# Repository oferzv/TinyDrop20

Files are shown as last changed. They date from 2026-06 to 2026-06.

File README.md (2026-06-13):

# TinyDrop20

TinyDrop20 is a small ATtiny85-based 5x4 charlieplexed LED matrix board. The
repository contains the PlatformIO firmware project, Eagle design files, and
manufacturing outputs for hardware revision `V1_1`.

## Project background

This project was created in collaboration with [@talofer99](https://github.com/talofer99)
as part of a series of free-time hardware and firmware projects we built years
ago. I decided to move these projects to GitHub in the hope that they may be
useful, educational, or inspiring to others.

This PCB revision was manufactured and tested.

## Repository layout

```text
Firmware/
  V1_1/
    platformio.ini      PlatformIO project configuration
    src/main.cpp        ATtiny85 firmware
    include/            Project headers, currently unused
    lib/                Project libraries, currently unused
    test/               PlatformIO test folder, currently unused

Hardware/
  V1_1/
    Eagle/              Eagle schematic and board files
    Manufacturing/
      GERBER/           Gerber package for PCB fabrication
      Schematic/        Exported schematic PDF
```

## Hardware overview

The V1.1 board is built around an `ATTINY85-20SU` microcontroller and a 20 LED
display arranged as a 5 row by 4 column matrix. The LEDs are 0603 green parts
driven through five 100 ohm resistors from ATtiny pins `PB0` through `PB4`.

Other notable hardware:

- 20 green 0603 matrix LEDs
- 1 red 0603 status LED
- ATtiny85 SOIC-8 microcontroller
- Five 100 ohm matrix resistors
- 10 kOhm reset pull-up resistor
- Micro USB connector
- MCP73831 battery charger circuit
- CR2450-size coin-cell holder footprint
- Six round test points for programming or probing
- 3.6 mm mounting pad

Power note: the schematic includes an MCP73831 Li-ion/LiPo charger and a battery
holder labeled `CR2450`. Standard CR2450 cells are not rechargeable. Before
connecting USB power with a cell installed, verify that the assembled board is
intended for a compatible rechargeable lithium coin cell, such as the exact cell
specified by the hardware build.

## Firmware overview

The firmware is an Arduino sketch built with PlatformIO for `attiny85` at
8 MHz. It drives the LEDs directly by changing ATtiny GPIO direction and output
state for charlieplexing.

Display constants in `Firmware/V1_1/src/main.cpp`:

```cpp
#define SPEED          35
#define DISPLAY_WIDTH  4
#define DISPLAY_HEIGHT 5
```

The sketch includes:

- A 4x5 bitmap font for uppercase letters, digits, space, `!`, `#`, `$`, and
  `^`
- `setLed()` and `setPixel()` helpers for charlieplexed LED control
- `renderCharacter()` and `renderString()` helpers for drawing text
- Several visual modes and effects:
  - `matrix_fill_test()`
  - `write_text()`
  - `scrolling_text()`
  - `screen_saver()`
  - `rainEffect()`
  - `rows_effect()`

The current sketch displays `myString`, defined near the top of `main.cpp`:

```cpp
char myString[] = "#$^";
```

In the checked-in firmware, `lastState` is hardcoded to `1`, so `setup()` sets
`mode = 0` and the main loop runs `matrix_fill_test()`. The EEPROM-based mode
toggle code is present but commented out.

## Build firmware

Install PlatformIO, then build from the firmware directory:

```powershell
cd Firmware\V1_1
pio run
```

Build output is generated under:

```text
Firmware/V1_1/.pio/build/attiny85/
```

The main outputs are `firmware.elf` and `firmware.hex`.

## Upload firmware

The PlatformIO environment is configured for a USBtiny-compatible ISP
programmer:

```ini
[env:attiny85]
platform = atmelavr
board = attiny85
framework = arduino
board_build.mcu = attiny85
board_build.f_cpu = 8000000L
upload_protocol = usbtiny
```

Connect the programmer to the ATtiny85 programming pads or test points, then
run:

```powershell
cd Firmware\V1_1
pio run -t upload
```

The Micro USB connector on the hardware is part of the board power and charger
circuit. The firmware configuration expects ISP programming with `usbtiny`, not
USB bootloader programming.

## Hardware files

Open the board in Autodesk Eagle/Fusion Electronics using:

```text
Hardware/V1_1/Eagle/TinyDrop20_V1_1.sch
Hardware/V1_1/Eagle/TinyDrop20_V1_1.brd
```

Manufacturing files are already exported:

```text
Hardware/V1_1/Manufacturing/GERBER/TinyDrop20_V1_1_2020_03_09.zip
Hardware/V1_1/Manufacturing/Schematic/TinyDrop20_V1_1.pdf
```

## Development notes

- The charlieplexing code uses ATtiny pins `0` through `4`, corresponding to
  `PB0` through `PB4` in the schematic.
- Only one LED is actively driven at a time. Persistent images are produced by
  repeatedly scanning pixels fast enough for persistence of vision.
- To show different text, update `myString` in `src/main.cpp`.
- To enable the text display mode, set `mode = 1` or re-enable the EEPROM mode
  selection logic.
- Generated PlatformIO build files under `.pio/` should not be committed.

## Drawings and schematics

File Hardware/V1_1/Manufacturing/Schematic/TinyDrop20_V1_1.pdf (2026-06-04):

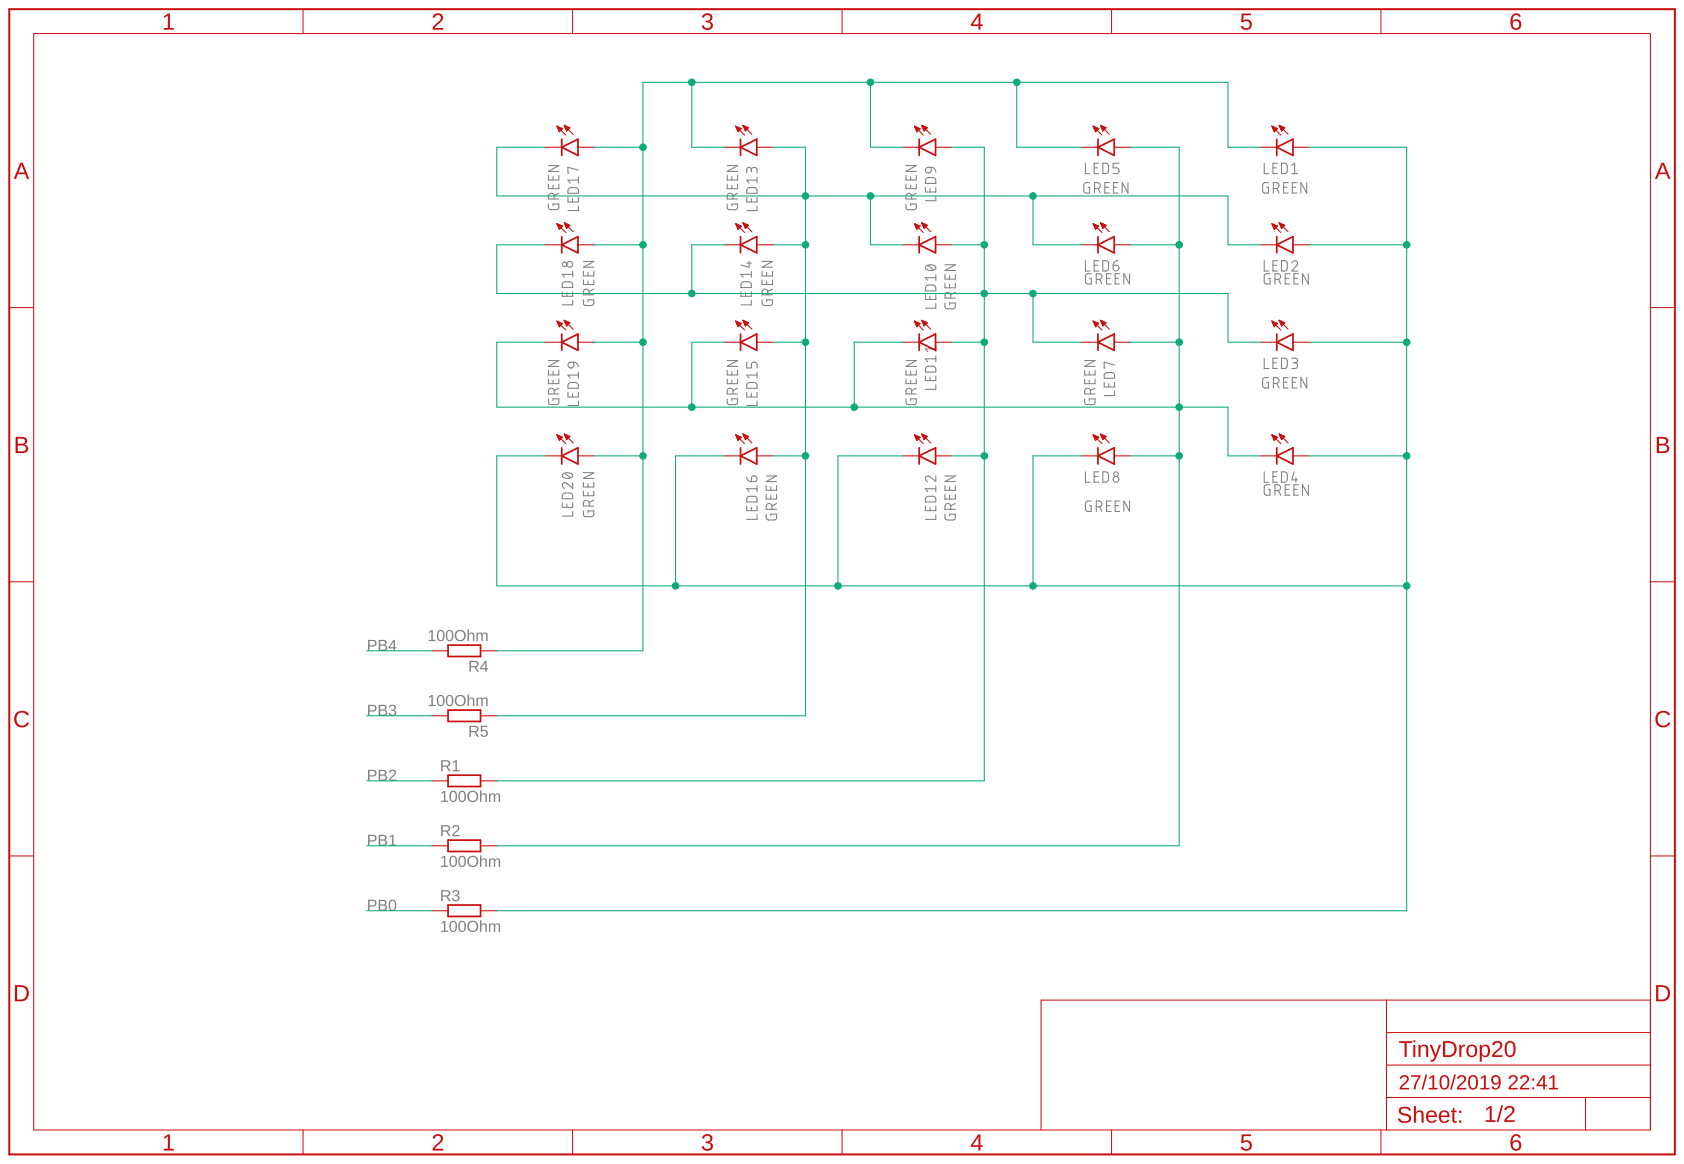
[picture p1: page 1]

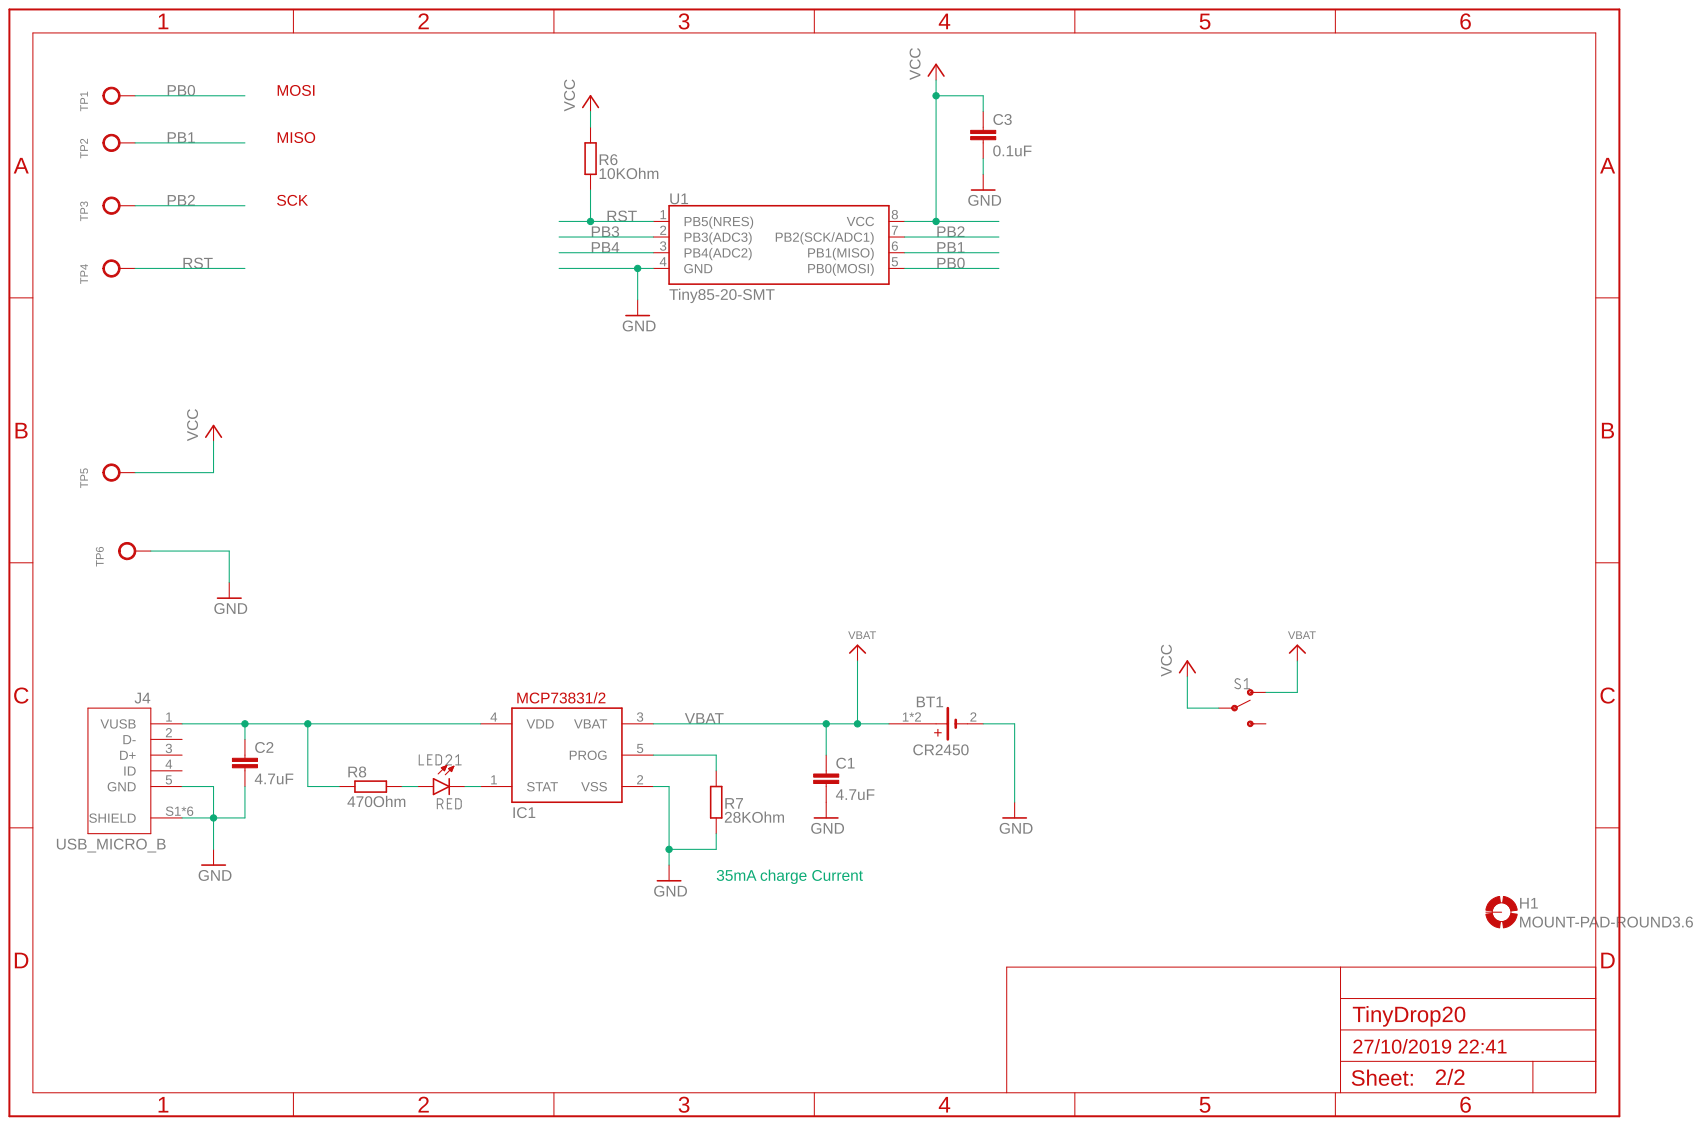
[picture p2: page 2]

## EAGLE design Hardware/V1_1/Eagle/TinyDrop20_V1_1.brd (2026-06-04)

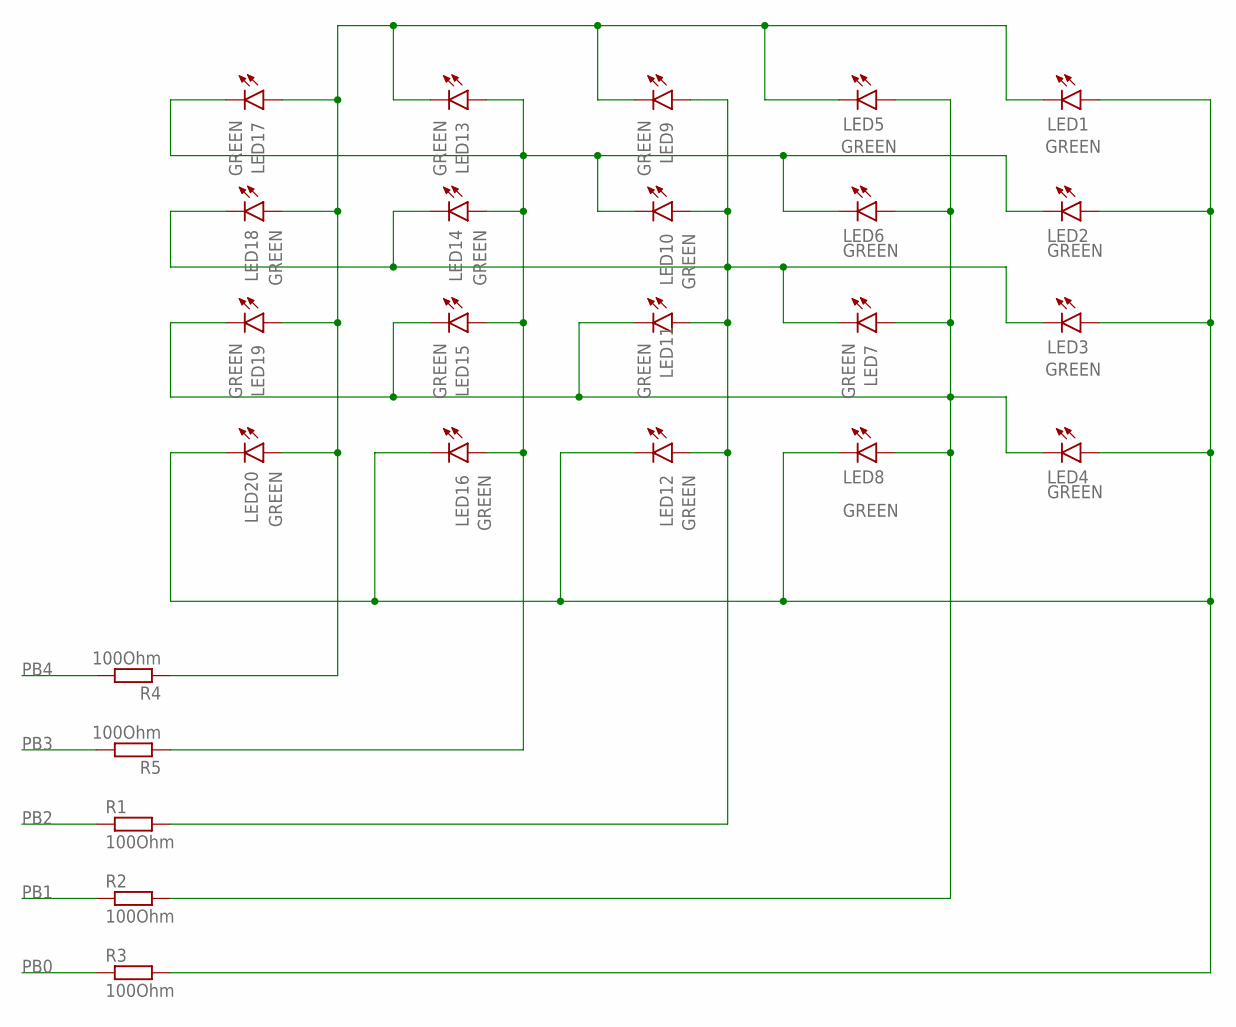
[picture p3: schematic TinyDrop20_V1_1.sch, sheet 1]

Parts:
LED1, LED2, LED3, LED4, LED5, LED6, LED7, LED8, LED9, LED10, LED11, LED12, LED13, LED14, LED15, LED16, LED17, LED18, LED19, LED20: GREEN; CHIPLED_0603
R1, R2, R3, R4, R5: 100Ohm; R0603

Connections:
unnamed: LED1.A, LED2.A, LED3.A, LED4.A, LED8.C, LED12.C, LED16.C, LED20.C, R3.2
unnamed: LED4.C, LED5.A, LED6.A, LED7.A, LED8.A, LED11.C, LED15.C, LED19.C, R2.2
unnamed: LED3.C, LED7.C, LED9.A, LED10.A, LED11.A, LED12.A, LED14.C, LED18.C, R1.2
unnamed: LED2.C, LED6.C, LED10.C, LED13.A, LED14.A, LED15.A, LED16.A, LED17.C, R5.1
unnamed: LED1.C, LED5.C, LED9.C, LED13.C, LED17.A, LED18.A, LED19.A, LED20.A, R4.1
PB0: R3.1; also elsewhere on the board
PB1: R2.1; also elsewhere on the board
PB2: R1.1; also elsewhere on the board
PB3: R5.2; also elsewhere on the board
PB4: R4.2; also elsewhere on the board

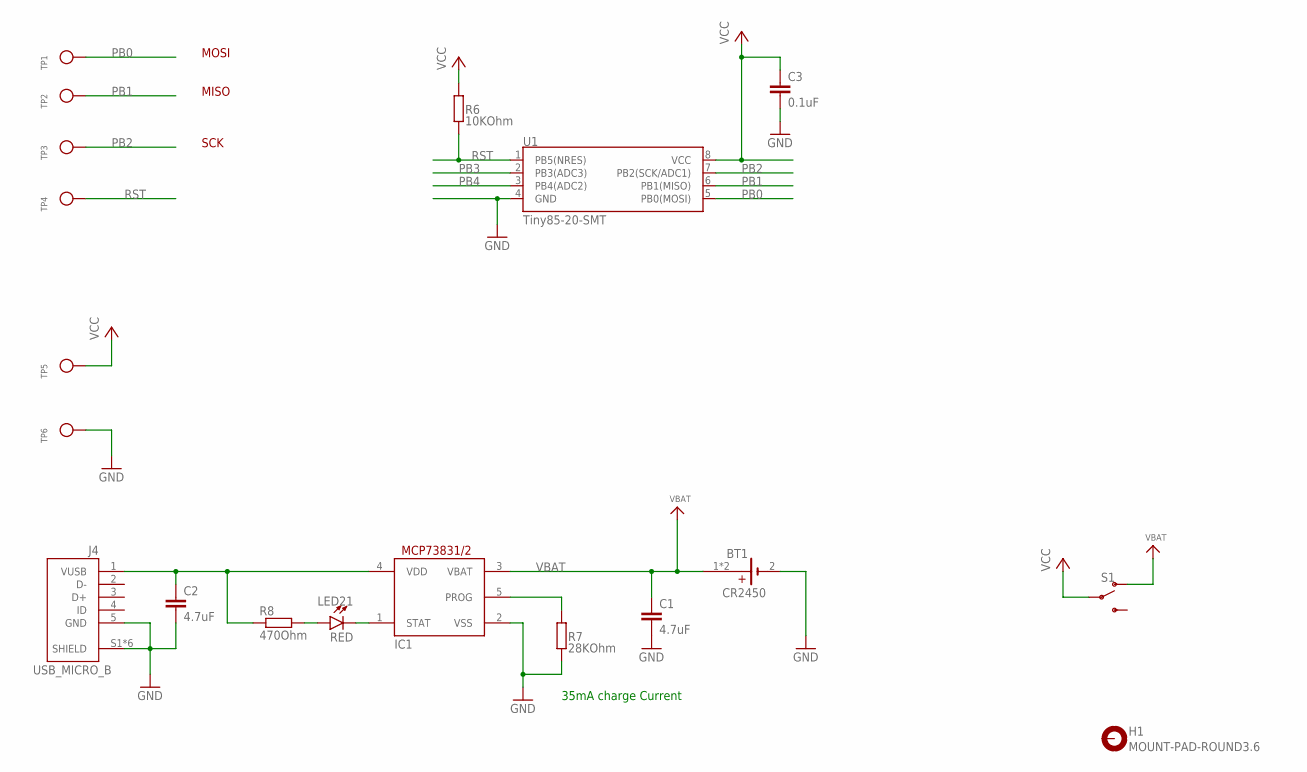
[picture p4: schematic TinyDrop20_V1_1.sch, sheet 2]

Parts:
BT1: CR2450; BATTCON_24.5X5MM_SMD
C1, C2: 4.7uF; C0805
C3: 0.1uF; C0805
H1: MOUNT-PAD-ROUND3.6; 3,6-PAD
IC1: MCP73831/OT; SOT23-5L
J4: USB_MICRO_B; FCI_10118193-0001LF
LED21: RED; CHIPLED_0603
R6: 10KOhm; R0603
R7: 28KOhm; R0603
R8: 470Ohm; R0603
S1: SWITCH-SPDT-SMD-RIGHT-ANGLE; SWITCH_SPST_SMD_A
TP1, TP2, TP3, TP4, TP5, TP6: TESTPOINTROUND2MM; TESTPOINT_ROUND_2MM
U1: Tiny85-20-SMT; SO08-EIAJ_MCU

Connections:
GND: BT1.2 (-), C1.2, C2.2, C3.2, IC1.2 (VSS), J4.5 (GND), J4.S1 (SHIELD), J4.S2 (SHIELD), J4.S3 (SHIELD), J4.S4 (SHIELD), J4.S5 (SHIELD), J4.S6 (SHIELD), R7.1, TP6.P$1, U1.4 (GND)
unnamed: IC1.5 (PROG), R7.2
unnamed: C2.1, IC1.4 (VDD), J4.1 (VUSB), R8.1
unnamed: IC1.1 (STAT), LED21.C
unnamed: LED21.A, R8.2
PB0: TP1.P$1, U1.5 (PB0(MOSI)); also elsewhere on the board
PB1: TP2.P$1, U1.6 (PB1(MISO)); also elsewhere on the board
PB2: TP3.P$1, U1.7 (PB2(SCK/ADC1)); also elsewhere on the board
PB3: U1.2 (PB3(ADC3)); also elsewhere on the board
PB4: U1.3 (PB4(ADC2)); also elsewhere on the board
RST: R6.1, TP4.P$1, U1.1 (PB5(NRES))
VBAT: BT1.1 (+), BT1.3 (+), C1.1, IC1.3 (VBAT), S1.1 (O)
VCC: C3.1, R6.2, S1.2, TP5.P$1, U1.8 (VCC)

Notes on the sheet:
35mA charge Current
MOSI
MISO
SCK

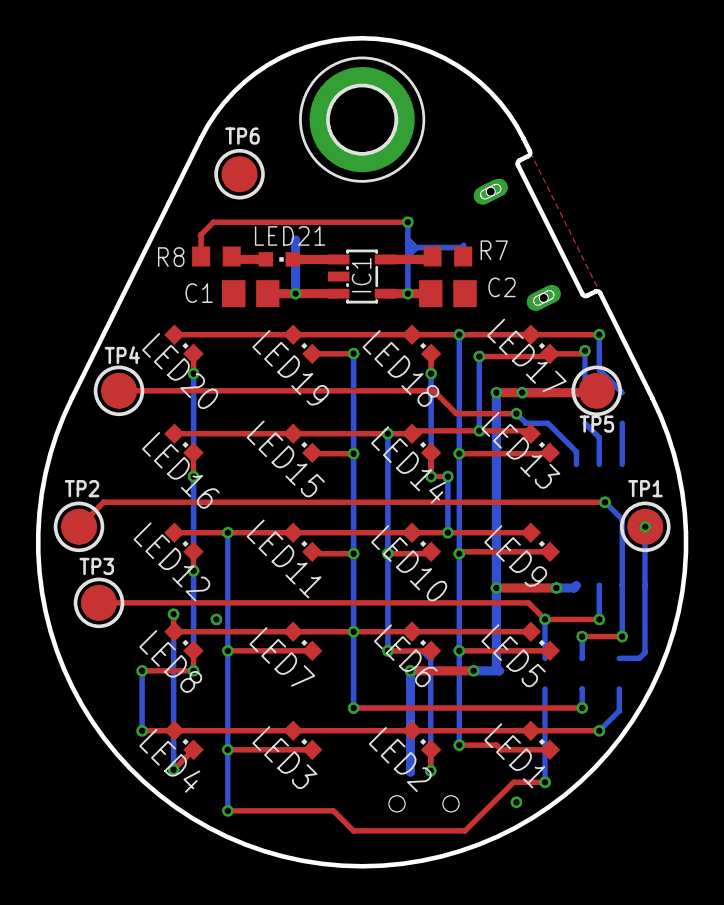
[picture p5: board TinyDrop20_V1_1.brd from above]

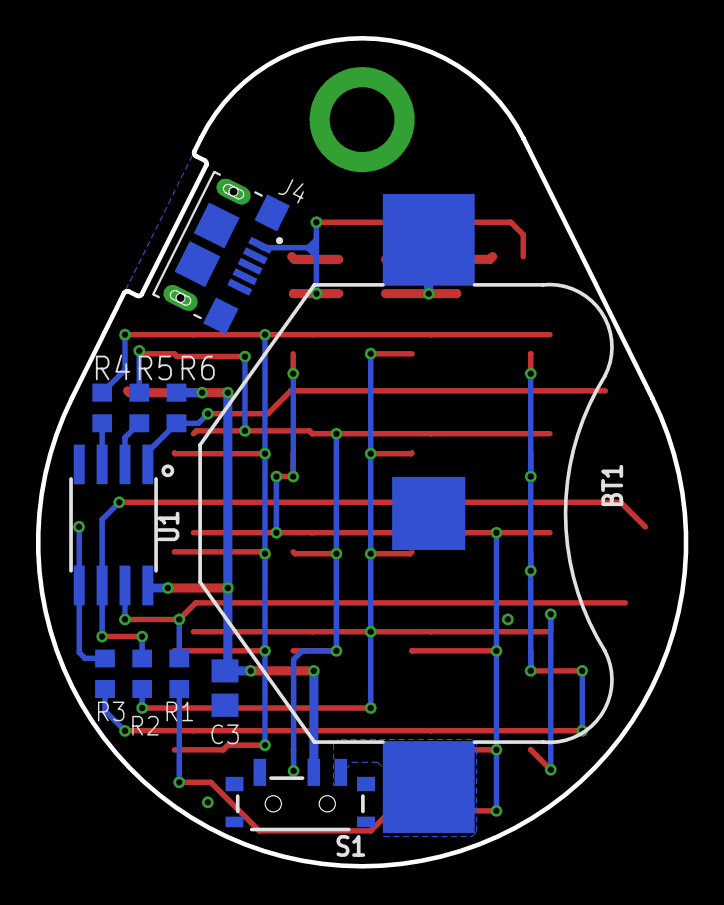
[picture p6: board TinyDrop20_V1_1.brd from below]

Board: 2 copper layers, 36.0 x 46.0 mm, 44 parts (11 on the bottom side), 18 nets.

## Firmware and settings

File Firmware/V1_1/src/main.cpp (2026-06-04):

#include <Arduino.h>
//#include <avr/eeprom.h>

// where does our characterMap start in the ASCII code
#define MAP_START      32
#define SPEED          35
#define DISPLAY_WIDTH  4
#define DISPLAY_HEIGHT 5

// maps characters to their 4x5 grid
unsigned long characterMap[59];

unsigned int timeout;
int offset = 0;
unsigned long lastMillis = 0;
unsigned long currentMillis = 0;

unsigned long graphic_t = 0b0;
unsigned long mil = 0;
byte counter = 0;
char myString[] = "#$^";
//char myString[] = "0 1 2 3 4 5 6 7 8 9";
int strLength = sizeof(myString);

byte x = 0;
byte y = 0;
int x_dir = 1;
int y_dir = 1;

int mode = 1;

// set up a character in the characterMap
void Chr(char theChar, unsigned long value) {
  characterMap[theChar - MAP_START] = value;
}

void scrolling_text();
void screen_saver();
int getNewDir();
void setLed(byte vin, byte gnd, boolean ledStatus);
void renderString(char *theString, int offset);
void matrix_fill_test() ;
void setPixel(byte x, byte y, boolean ledStatus);
void renderCharacter(char theChar, int charOffset);
void write_text();
void rainEffect();
void rows_effect();

void setup() {
#if defined(ARDUINO_AVR_UNO)
  Serial.begin(115200);
  Serial.println("System started");
#endif

int lastState = 1;//EEPROM.read(0);

if (lastState == 0)
{
  mode = 1;
  //EEPROM.update(0, mode);
}else if (lastState == 1)
{
  mode = 0;
//  EEPROM.update(0, mode);
}else
{
  //EEPROM.update(0, 1);
}

  // Rows:   1---2---3---4---5---
  Chr('A', 0b01101001111110011001);
  Chr('B', 0b11101001111010011110);
  Chr('C', 0b01111000100010000111);
  Chr('D', 0b11101001100110011110);
  Chr('E', 0b11111000111010001111);
  Chr('F', 0b11111000111010001000);
  Chr('G', 0b01111000101110010110);
  Chr('H', 0b10011001111110011001);
  Chr('I', 0b01110010001000100111);
  Chr('J', 0b01110010001010100100);
  Chr('K', 0b10011010110010101001);
  Chr('L', 0b10001000100010001111);
  Chr('M', 0b10011111111110011001);
  Chr('N', 0b10011101101110011001);
  Chr('O', 0b01101001100110010110);
  Chr('P', 0b11101001111010001000);
  Chr('Q', 0b01101001101101100001);
  Chr('R', 0b11101001111010101001);
  Chr('S', 0b11111000111100011111);
  Chr('T', 0b01110010001000100010);
  Chr('U', 0b10011001100110010110);
  Chr('V', 0b10011001100110100100);
  Chr('W', 0b10011001111111110110);
  Chr('X', 0b10011001011010011001);
  Chr('Y', 0b10011001011000101100);
  Chr('Z', 0b11110001001001001111);
  Chr(' ', 0b00000000000000000000);
  Chr('!', 0b01000100010000000100);
  Chr('1', 0b01001100010001001110);
  Chr('2', 0b11110001011010000111);
  Chr('3', 0b11100001011000011110);
  Chr('4', 0b00100110101011110010);
  Chr('5', 0b11111000111000011110);
  Chr('6', 0b01101000111010010110);
  Chr('7', 0b11110001001001001000);
  Chr('8', 0b01101001011010010110);
  Chr('9', 0b01101001011100010110);
  Chr('0', 0b01101001110110110110);
  Chr('#', 0b11111111111111111111);
  Chr('$', 0b00000000011000000000);
  Chr('^', 0b00000110011001100000);
  randomSeed(analogRead(A0));

  // how long to wait between shifting the display
  timeout = 1000 / SPEED;
  mil = millis();

}



void loop() {
  // scrolling text from myString
  // scrolling_text();
switch (mode)
{
case 0:
  matrix_fill_test();
  break;
case 1:
  write_text();
  break;
default:
  break;
}


  // rainEffect();
  // ping pong pretty effect
    // screen_saver();
  //singale letter at a time myString
  // write_text();

  // matrix fill test
  //  matrix_fill_test();
  //  rows_effect();

}

void rainEffect()
{
   byte x =random(0,DISPLAY_WIDTH);
  // for (byte x = 0 ; x < DISPLAY_WIDTH; x++ )
  // {
    for(int y = DISPLAY_HEIGHT-1; y >= 0 ; y--)
    {
      setPixel(x, y, HIGH);
      delay(3);
    }
    delay(10);
  // }

  // for (byte x = 0; x < DISPLAY_WIDTH ;x++ )
  // {
  //   for(byte y = 0; y < DISPLAY_HEIGHT; y++)
  //   {
  //     setPixel(x, y, LOW);
  //     // delay(50);
  //   }
  // }

}

void rows_effect(){
  for (byte y = 0; y < DISPLAY_HEIGHT ;y++)
  {
    for (byte x = 0 ; x < DISPLAY_WIDTH; x++)
    {
      setPixel(x, y, HIGH);
    }
    delay(100);
    for (byte x = 0 ; x < DISPLAY_WIDTH; x++)
    {
      setPixel(x, y, LOW);
    }
  }

  // for (byte x = 0 ; x < DISPLAY_WIDTH; x++ )
  // {
  //   for(byte y = DISPLAY_HEIGHT-1; y >= 0 ; y--)
  //   {
  //     setPixel(x, y, HIGH);
  //     delay(5);
  //   }
  //   delay(10);
  //   for(int y = DISPLAY_HEIGHT-1; y >= 0 ; y--)
  //   {
  //     setPixel(x, y, LOW);
  //   }
  // }
}




void scrolling_text() {
  currentMillis = millis();

  renderString(myString, offset);

  if (currentMillis - lastMillis > timeout) {
    lastMillis = currentMillis;
    // shift string over one "pixel"
    offset++;
    // if it's past the length of the string, start over from the beginning
    if (offset > strLength * (DISPLAY_WIDTH + 1)) {
      offset = -DISPLAY_WIDTH;
    }
  }
}


void screen_saver() {
  setPixel(x, y, 1);

  if (mil + 150 < millis()) {
    x += x_dir;
    y += y_dir;

    if (x <= 0 && x_dir == -1 ) {
      x_dir = 1;
      x = 0;
      //y_dir = getNewDir();
    }
    else if (x >= DISPLAY_WIDTH && x_dir == 1 )
    {
      x_dir = -1;
      x = DISPLAY_WIDTH - 2;
      //y_dir = getNewDir();
    }


    if (y <= 0 && y_dir == -1 ) {
      y_dir = 1;
      y = 0;
      //x_dir = getNewDir();
    }
    else if (y >= DISPLAY_HEIGHT && y_dir == 1 )
    {
      y_dir = -1;
      y = DISPLAY_HEIGHT - 2;
      //x_dir = getNewDir();
    }

    //DISPLAY_HEIGHT


    mil = millis();


  }

}

int getNewDir() {
  byte d = random(2);
  if (d)
    return 1;
  else
    return -1;
}

// light a pixel at the given coordinates
void setPixel(byte x, byte y, boolean ledStatus) {
  if (x >= 0 && x < DISPLAY_WIDTH) {
    if (y <= x) {
      x++;
    }
    setLed(y, x, ledStatus);
  }
}

// turn on the pins to light a LED
void setLed(byte vin, byte gnd, boolean ledStatus) {
  //delay(1);
  DDRB = 0;
  PORTB = 0;
  if (!ledStatus) return;

  pinMode(vin, OUTPUT);
  pinMode(gnd, OUTPUT);
  digitalWrite(vin, HIGH);
  digitalWrite(gnd, LOW);
}


// render the string on the given offset
void renderString(char *theString, int offset) {
  int index = 0;
  while (theString[index]) {
    renderCharacter(theString[index], offset - index * (DISPLAY_WIDTH + 1));
    index++;
  }
}

// render a character on the given offset
void renderCharacter(char theChar, int charOffset) {
  if (charOffset <= -DISPLAY_WIDTH || charOffset > DISPLAY_WIDTH) {
    // off the 'screen' nothing to do
    return;
  }

  unsigned long graphic = characterMap[theChar - MAP_START];

  for (byte y = 0; y < DISPLAY_HEIGHT; y++) {
    for (byte x = 0; x < DISPLAY_WIDTH; x++) {
      // 3 - x to reverse order
      setPixel(3 - x - charOffset, y, graphic & 0x1);
      graphic = graphic >> 1;
    }
  }
}

void test_screen(unsigned long graphic) {

  byte charOffset = 0;
  for (byte y = 0; y < DISPLAY_HEIGHT; y++) {
    for (byte x = 0; x < DISPLAY_WIDTH; x++) {
      // 3 - x to reverse order
      setPixel(3 - x - charOffset, y, graphic & 0x1);
      graphic = graphic >> 1;
    }
  }
}


void matrix_fill_test() {
  test_screen(graphic_t);
  if (mil + 50 < millis()) {
    graphic_t = graphic_t | (1UL << counter);
#if defined(ARDUINO_AVR_UNO)
    Serial.println(graphic_t, BIN);
#endif

    mil = millis();
    if (counter < 20) {
      counter++;
    }
    else
    {
      counter = 0;
      graphic_t = 0;
    }
  }
}

void write_text() {
  renderCharacter(myString[counter], 0);
  if (mil + 50 < millis()) {
    mil = millis();
    if (counter < strLength - 2) {
      counter++;
    }
    else
    {
      counter = 0;
    }
  }

}

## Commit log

2026-06-04 Eagle project files of the manufactured version
    [TinyDrop20_V1_1.brd, TinyDrop20_V1_1.sch]
2026-06-04 Adding Schematic PDF file
2026-06-13 Add PCB manufacturing note

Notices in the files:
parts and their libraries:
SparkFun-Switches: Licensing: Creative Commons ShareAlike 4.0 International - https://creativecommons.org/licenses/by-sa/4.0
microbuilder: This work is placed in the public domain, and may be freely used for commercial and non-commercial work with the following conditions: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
